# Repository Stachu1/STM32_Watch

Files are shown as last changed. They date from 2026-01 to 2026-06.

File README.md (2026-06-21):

# STM32 Watch


A minimalist, bare-metal wristwatch built around an STM32L0 microcontroller.
No HAL, no RTOS, no libraries. Just registers.

This is a fully custom PCB watch powered by a CR2032 coin cell, using 12 discrete LEDs arranged like a traditional analog dial. Time is displayed using LED “hands”, with additional modes for voltage, temperature, time setting, and a physics-based pendulum simulation.

## Features

### Core

- Ultra-low-power (STM32 Cortex-M0+)
- Bare-metal firmware
- RTC-based timekeeping using LSE (32.768 kHz)
- 12 discrete LEDs forming a clock dial
- Time-division multiplexing for LED control
- Two buttons for mode switching and wake-up from sleep

### Optional with IMU

- Absolute wrist tilt (AWT) wake-up
- Double tap to change LED brightness
- Pendulum simulation

## Modes

### Time display

- Hour hand: Static LED
- Minute hand: Slow fade in and out
- Subminutes (full rotation every 5min) hand: Quick fade in and out

### Statistics (Battery voltage, IMU/MCU temperature)

Battery voltage = Hour / 10 + 2V

(If hour hand is at 9 the battery voltage is 0.9V + 2V = 2.9V)

IMU/MCU temperature = Hour * 5°C + Minute * 0.1°C

(If hour hand is at 4 and minute hand is at 35 the temperature is 4 * 5°C + 35 * 0.1°C = 23.5°C)

### Time setting

Hour hand running in a circle indicated you are in the time setting mode.
Press Upper button to go into hour setting then press lower button to move the hour hand form 12 to 1, 2, 3 up to the current time. Confirm with the Upper button. Reapeat for minutes. After confirming minutes the watch will go back to Time display mode.

### Pendulum simulation

If the LEDs at 3 and 9 blink the IMU is disabled. You can enable it by pressing both buttons at once. This will enable the IMU and change mode to Time display.

IF the IMU is enbaled ther hour hand will behave like a pendulum with very low friction. I reacts to the acceleration vector in the XY plane so either tilting or moving the watch arround can cause the hour hand to move.

By double tapping the watch you can add 5 rotations a seconds to the pendulum in the current rotation direction.

If you wanna disalbe the IMU just press both buttons at once. The watch will disable the IMU and go back to the Time display mode.

## Mode changing

| *Current Mode* | *Action* | *Effect* |
|:-: | :-: | :- |
| Time display | Upper button | Change brightness |
| Time display | Double tap | Change brightness (if IMU enabled) |
| Time display | Lower button | Change mode to Stats (battery voltage) |
| Statistics | Upper button | Cycle stats (voltage/temperature) |
| Statistics | Lower button | Change mode to Time setting |
| Time setting | Upper button | Set hour/minute or confirm and change mode to Time display |
| Time setting | Lower button | Change mode to Pendulum simulation or increment hour/minute hand |
| Pendulum simulation | Upper button | Change brightness |
| Pendulum simulation | Double tap | Add +/- 5 rotations/second to the pendulum speed |
| Pendulum simulation | Upper & Lower buttons | Enable/Disable IMU (All the IMU features won't work if the IMU is disabled) |
| Pendulum simulation | Lower button | Change mode to Time display |

## Power Consumption

Tested on a CR2032 @ ~2.9V

| *Mode* | *Current* | *Wakeup* |
|:-: | :-: | :-: |
| Active (display on) | ~3mA | - |
| Stop mode (sleep) | 22uA | AWT or Buttons |
| Ultra low power (IMU off) | 5.5uA | Buttons |
| Stop mode, no IMU mounted | 2.3uA | Buttons |

## Hardware

- MCU: STM32L031
- IMU: LSM6DSM
- Timekeeping: built-in RTC with an external 32.768 kHz crystal
- Ambient light sensor (reverse-biased LED)
- Time display: 12 discrete LEDs
- Two push buttons
- Powered by a CR2032 battery








All LEDs are connected to ground through a single 100 Ω resistor, which is acceptable because only one LED is on at a time.

The RST pin has a single 100 nF capacitor, as there is an internal pull-up (~40 kΩ).

The I2C lines have external 10 kΩ pull-ups, but it would likely be possible to use weaker internal pull-ups if the frequency were reduced (not tested).

On the back side of the PCB, there are test points for SWD programming and UART debugging.

## Firmware

This project is intentionally low-level:

* Direct register access only
* No abstraction layers
* Tight control over timing and power
* Interrupt-driven architecture
* Fixed-point arithmetic (Q16.16)

### LED Driving

LEDs are updated in the IRQ handler, which runs every 100 µs. If a hand is to be shown, the LED is turned on at the beginning of its time slot and turned off when `local_step` reaches the hand’s brightness or at the end of the time slot. This approach ensures that only one LED is on at a time, limiting peak current and reducing battery voltage drop.

### Timekeeping

The STM32’s RTC runs on the low-speed external oscillator, and the time can be set by the user. Due to the high ESR of the crystal, the LSE drive strength had to be set to medium-high (`LSEDRV` in `RCC_CSR`).

### Sensors

The two interrupt pins on the LSM6DSM are used to detect double tap and absolute wrist tilt. Double tap is only available when the watch is awake, as it requires a significantly higher sampling rate.

Battery voltage is measured by reading the internal voltage reference and calculating the supply voltage. This works well, but due to the high internal resistance of the battery, the measured value is about 100 mV lower than the actual open-circuit voltage.

Temperature is measured using the IMU if it is enabled, or the internal temperature sensor of the MCU otherwise.

Ambient light sensing is not currently used, but it can be implemented by setting the pin connected to a reverse-biased LED high and then switching it to high-impedance input. The brighter it is, the faster the pin returns to a low state. Unfortunately, in very dark conditions this can take hundreds of milliseconds, which is why it is not used.

## Build System

This project uses a minimal build setup based on `build.c` and a nobuild-style workflow:
[https://github.com/tsoding/nob.h](https://github.com/tsoding/nob.h)

---

### Build

```bash
cd firmware
clang build.c -o build
./build build
```

---

### Build & Flash (ST-LINK + OpenOCD)

Solder ST-LINK SWD connections to the test points on the back. (Or just hold a pinheader on them)

```bash
./build flash
```

You can also flash the firmware using STM32CubeProgrammer.

---

## Firmware Size

```
text    data     bss     dec     hex filename
10304     56    4160   14520    38b8 firmware.elf
```

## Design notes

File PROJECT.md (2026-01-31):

# STM32 Watch:
This project is about maing a PCB watch that is based around an STM32, runs on a CR2032 battery, and displays time with 12 leds aranged in a circle. (Kinda like mechanical watches)

The goal is to learn more about PCB desing, STM32 enviorment and low-power features.

## Rev: A

### Features
* Powered by a CR2032
* STM32 MCU with SWD & UART communication
* The watch has two buttons
* Time is displayed through 12 leds arranged on a circle
* Ambiend light sensing
* IMU can be set into low-power and acceleratin can be read
* Wrist up interrupt detection
* Gesture control

### Buttons funcions
* Wake up from standby
* Time can be set
* Battery voltage can be checked
* Brightnes can be checked (1 - 2 - 3 - auto)
* Particle sim with a single LED showing a particle that reacts to watch acceleration
* Core tmeperature can be checked

### Finish Rev A by the end of March 2026

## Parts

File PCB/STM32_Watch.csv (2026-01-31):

Reference | Value | Footprint | Datasheet | Qty | LCSC | DNP | Exclude from BOM | Exclude from Board
BT1 | Battery_Cell | Battery:BatteryHolder_Renata_SMTU2032-LF_1x2032 | ~ | 1 | C18212226
C1,C4,C5,C6,C10,C11 | 100n | Capacitor_SMD:C_0603_1608Metric | ~ | 6 | C14663
C2,C3 | 18p | Capacitor_SMD:C_0603_1608Metric | ~ | 2 | C1647
C7 | 10u | Capacitor_SMD:C_0805_2012Metric | ~ | 1 | C32635
C8,C9 | 100u | Capacitor_SMD:C_1206_3216Metric | ~ | 2 | C15008
D1,D2,D3,D4,D5,D6,D7,D8,D9,D10,D11,D12,D13 | LED | LED_SMD:LED_0603_1608Metric | ~ | 13 | C965799
H1,H2 | MountingHole | STM32_Watch:StrapsConnection_20mm | ~ | 2 |  |  | Excluded from BOM
R1,R3,R4 | 10k | Resistor_SMD:R_0603_1608Metric | ~ | 3 | C98220
R2 | 100 | Resistor_SMD:R_0603_1608Metric | ~ | 1 | C105588
R5 | 1M | Resistor_SMD:R_0603_1608Metric | ~ | 1 | C105578
SW1,SW2 | SW_Push | STM32_Watch:SHOU_HAN_TS24CA |  | 2 | C393942
TP1,TP3,TP4,TP5,TP6,TP7,TP8 | TestPoint_Small | TestPoint:TestPoint_Pad_D1.5mm | ~ | 7
U1 | STM32L031K6Ux | Package_DFN_QFN:QFN-32-1EP_5x5mm_P0.5mm_EP3.1x3.1mm_ThermalVias | https://www.st.com/resource/en/datasheet/stm32l031k6.pdf | 1 | C2969821
U2 | LSM6DS3 | Package_LGA:LGA-14_3x2.5mm_P0.5mm_LayoutBorder3x4y | https://www.st.com/resource/en/datasheet/lsm6ds3tr-c.pdf | 1 | C94048
X1 | 32.768k | Crystal:Crystal_SMD_3215-2Pin_3.2x1.5mm |  | 1 | C5120559

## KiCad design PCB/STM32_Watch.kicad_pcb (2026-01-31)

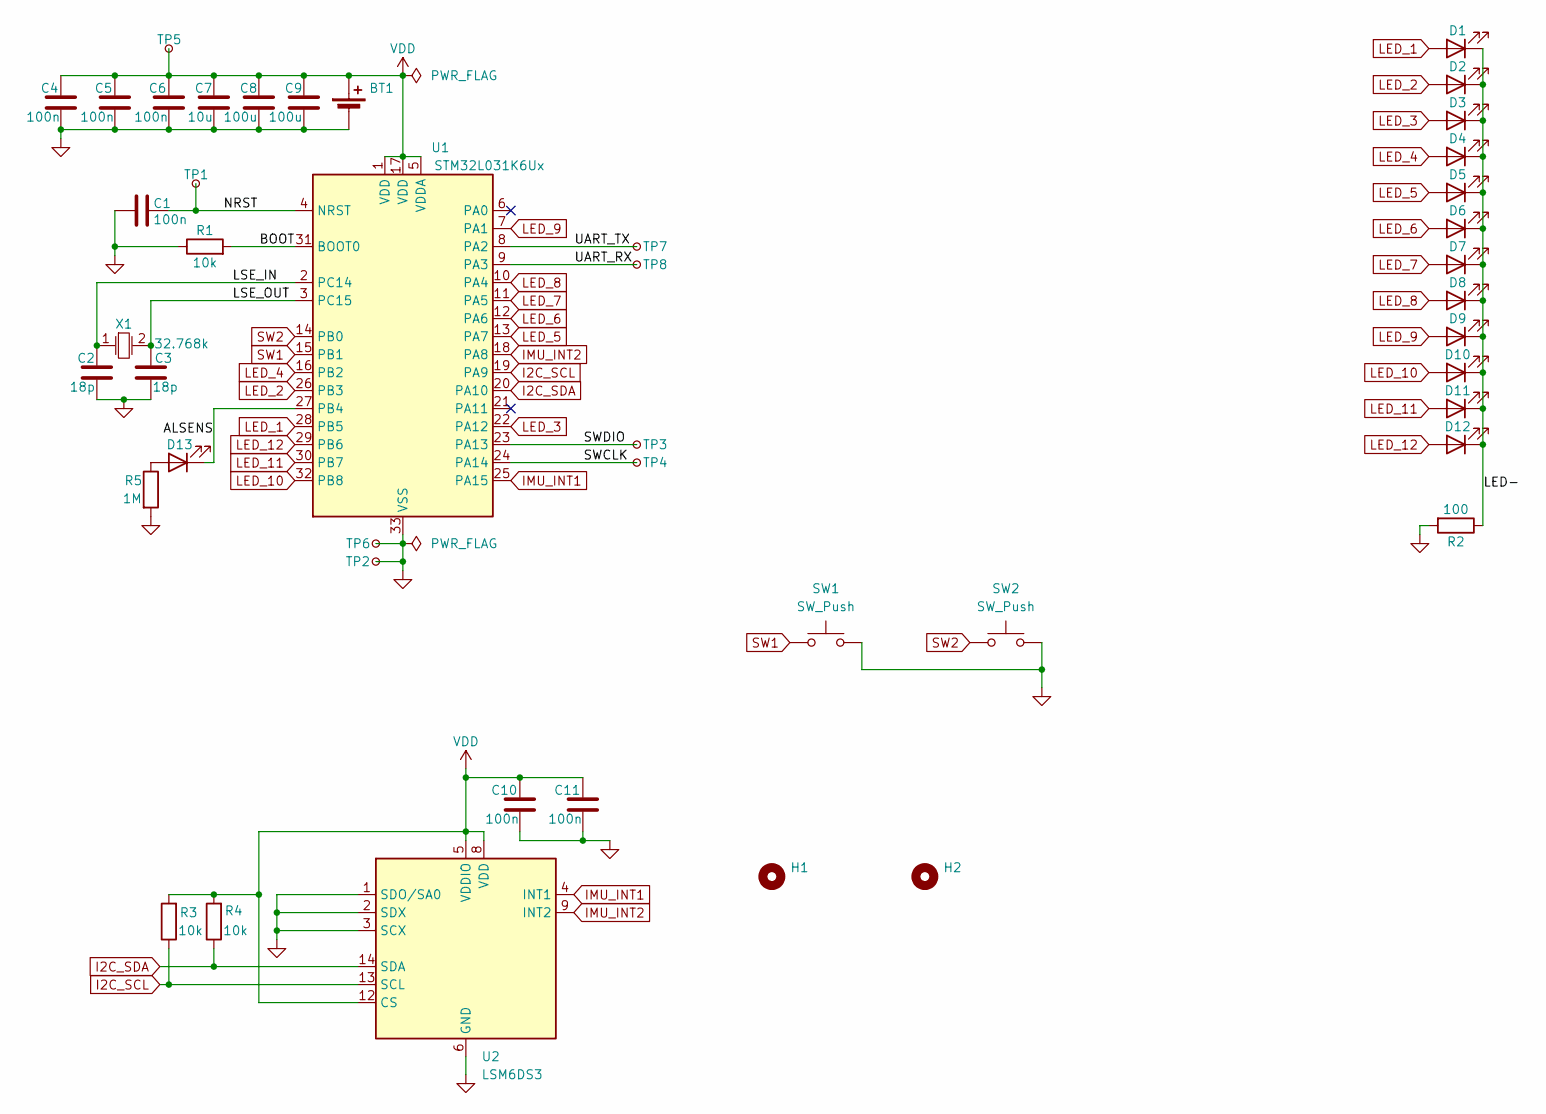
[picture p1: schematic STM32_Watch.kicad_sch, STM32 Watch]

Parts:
BT1: Battery_Cell; BatteryHolder_Renata_SMTU2032-LF_1x2032; LCSC C18212226
C1, C4, C5, C6, C10, C11: 100n; C_0603_1608Metric; LCSC C14663
C2, C3: 18p; C_0603_1608Metric; LCSC C1647
C7: 10u; C_0805_2012Metric; LCSC C32635
C8, C9: 100u; C_1206_3216Metric; LCSC C15008
D1, D2, D3, D4, D5, D6, D7, D8, D9, D10, D11, D12, D13: LED; LED_0603_1608Metric; LCSC C965799
H1, H2: MountingHole; StrapsConnection_20mm
R1, R3, R4: 10k; R_0603_1608Metric; LCSC C98220
R2: 100; R_0603_1608Metric; LCSC C105588
R5: 1M; R_0603_1608Metric; LCSC C105578
SW1, SW2: SW_Push; SHOU_HAN_TS24CA; LCSC C393942
TP1, TP2, TP3, TP4, TP5, TP6, TP7, TP8: TestPoint_Small; TestPoint_Pad_D1.5mm
U1: STM32L031K6Ux; QFN-32-1EP_5x5mm_P0.5mm_EP3.1x3.1mm_ThermalVias; LCSC C2969821
U2: LSM6DS3; LGA-14_3x2.5mm_P0.5mm_LayoutBorder3x4y; LCSC C94048
X1: 32.768k; Crystal_SMD_3215-2Pin_3.2x1.5mm; LCSC C5120559

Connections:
/ALSENS: D13.1 (K), U1.27 (PB4)
/BOOT: R1.2, U1.31 (BOOT0)
/LED-: D1.1 (K), D2.1 (K), D3.1 (K), D4.1 (K), D5.1 (K), D6.1 (K), D7.1 (K), D8.1 (K), D9.1 (K), D10.1 (K), D11.1 (K), D12.1 (K), R2.1
/LSE_IN: C2.2, U1.2 (PC14), X1.1
/LSE_OUT: C3.2, U1.3 (PC15), X1.2
/NRST: C1.1, TP1.1, U1.4 (NRST)
/SWCLK: TP4.1, U1.24 (PA14)
/SWDIO: TP3.1, U1.23 (PA13)
/UART_RX: TP8.1, U1.9 (PA3)
/UART_TX: TP7.1, U1.8 (PA2)
GND: BT1.2 (-), C1.2, C2.1, C3.1, C4.2, C5.2, C6.2, C7.2, C8.2, C9.2, C10.2, C11.2, R1.1, R2.2, R5.2, SW1.2, SW2.2, TP2.1, TP6.1, U1.33 (VSS), U2.1 (SDO/SA0), U2.2 (SDX), U2.3 (SCX), U2.6 (GND), U2.7 (GND)
I2C_SCL: R3.1, U1.19 (PA9), U2.13 (SCL)
I2C_SDA: R4.1, U1.20 (PA10), U2.14 (SDA)
IMU_INT1: U1.25 (PA15), U2.4 (INT1)
IMU_INT2: U1.18 (PA8), U2.9 (INT2)
LED_1: D1.2 (A), U1.28 (PB5)
LED_2: D2.2 (A), U1.26 (PB3)
LED_3: D3.2 (A), U1.22 (PA12)
LED_4: D4.2 (A), U1.16 (PB2)
LED_5: D5.2 (A), U1.13 (PA7)
LED_6: D6.2 (A), U1.12 (PA6)
LED_7: D7.2 (A), U1.11 (PA5)
LED_8: D8.2 (A), U1.10 (PA4)
LED_9: D9.2 (A), U1.7 (PA1)
LED_10: D10.2 (A), U1.32 (PB8)
LED_11: D11.2 (A), U1.30 (PB7)
LED_12: D12.2 (A), U1.29 (PB6)
unnamed: D13.2 (A), R5.1
SW1: SW1.1, U1.15 (PB1)
SW2: SW2.1, U1.14 (PB0)
VDD: BT1.1 (+), C4.1, C5.1, C6.1, C7.1, C8.1, C9.1, C10.1, C11.1, R3.2, R4.2, TP5.1, U1.1 (VDD), U1.5 (VDDA), U1.17 (VDD), U2.5 (VDDIO), U2.8 (VDD), U2.12 (CS)

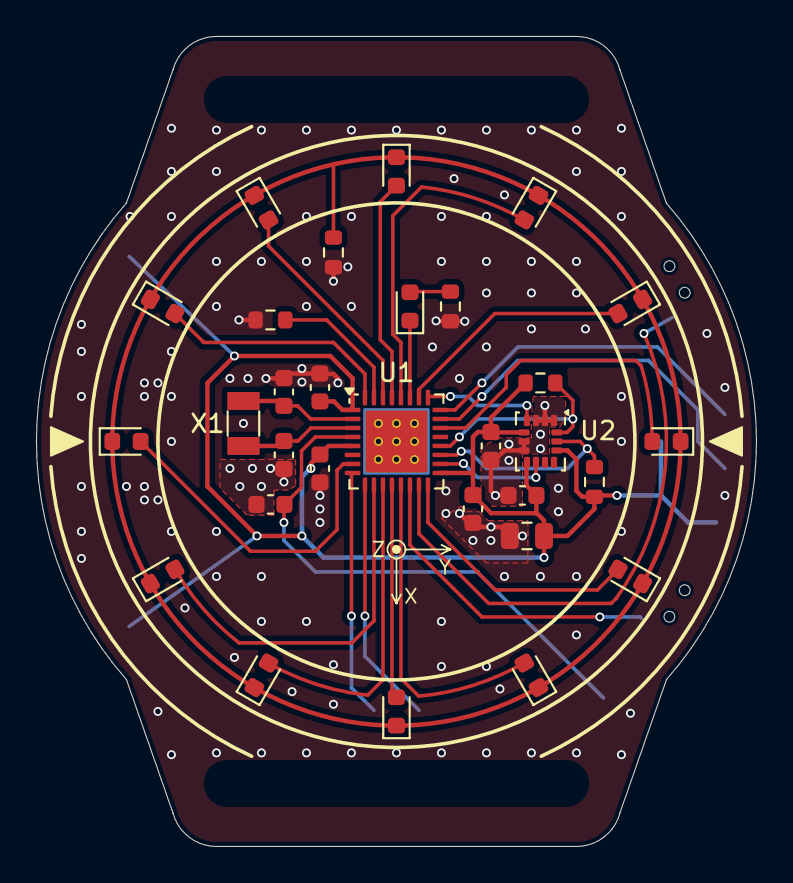
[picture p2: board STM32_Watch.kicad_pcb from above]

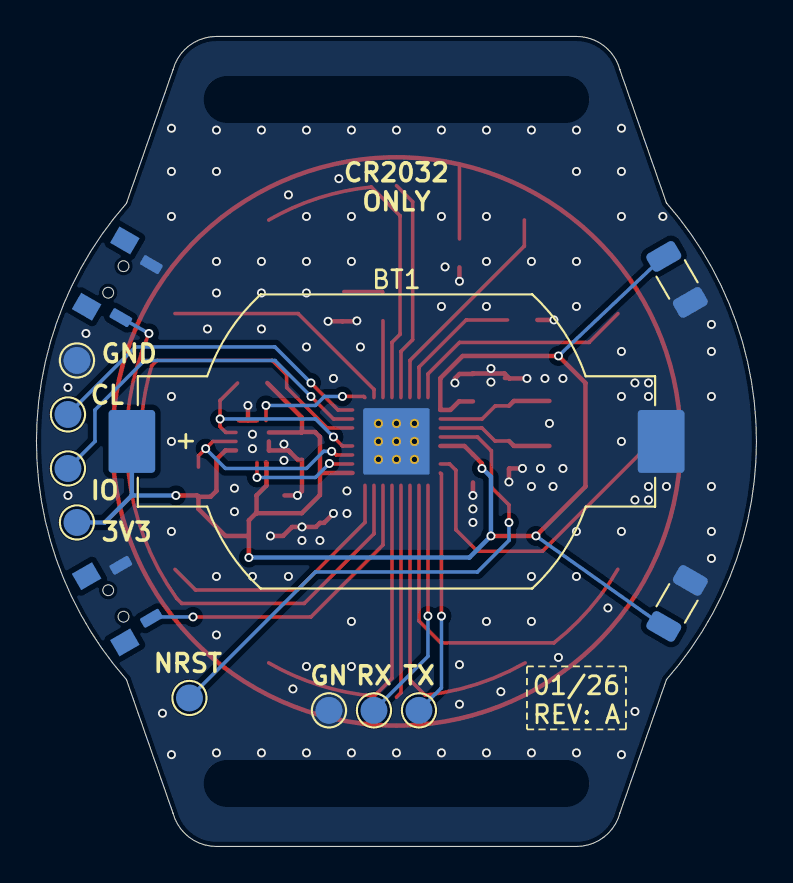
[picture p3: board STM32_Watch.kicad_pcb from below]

Board: 2 copper layers, 40.0 x 45.0 mm, 45 parts (13 on the bottom side), 31 nets.

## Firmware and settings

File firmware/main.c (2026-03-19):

#include "stm32l0x1_peripherals.h"
#include "intrin.h"
#include "types.h"

#define EVER (;;)
#define SYSCLK 2097000
#define BAUD 115200
#define TS_CAL1 *((u16*) 0x1FF8007A)
#define TS_CAL2 *((u16*) 0x1FF8007E)
#define VREFINT_CAL *((u16*) 0x1FF80078)
#define FIXED_SHIFT 16
#define FIXED_ONE (1 << FIXED_SHIFT)
#define IMU_ADDR 0x6A               // I2C address of the LSM6DSM IMU (SA0 pulled low)
#define MAX_BRIGHTNESS_LEVEL 6      // 1 << MAX_BRIGHTNESS_LEVEL = BRIGHTNESS_STEPS
#define MIN_BRIGHTNESS_LEVEL 3      // Lowest brightness level (too low causes flickering and instability in the effect)
#define BRIGHTNESS_STEPS (1 << MAX_BRIGHTNESS_LEVEL) // Number of steps in the brightness control (Impacts frame rate)
#define STATS_FRAME_TIME 50         // ms between each frame in the stats animation
#define SIM_DT 8                    // ms between each physics update in pendulum sim mode
#define SIM_FRICTION 160            // Friction applied to pendulums in pendulum sim mode (Q32)
#define SIM_AFTER_TAP_SPEED 327680  // Speed the pendulum is set to on double tap in pendulum sim mode (Q32)
#define SIM_INACTIVITY_THS 5500     // min speed before entering Stop Mode (Q32)1 = 2*Pi/s
#define INACTIVITY_TIMEOUT 5000     // ms of inactivity before entering Stop Mode
#define STATS_TIMEOUT 10000         // ms before switching entering Stope Mode from stats mode due to inactivity
#define DEBUG false                 // Set to true to enable debug prints over UART
#define USE_IMU true                // Set to false to disable IMU for ULP mode or if IMU is not mounted


typedef i32 q32;

typedef struct {
    u8 new_position;        // New position to set the hand to (1->12 0 for off)
    u8 position;            // position of the hand (1-12 0 for off)
    u8 brightness;          // Brightness of the hand (0-(BRIGHTNESS_STEPS-1))
    u8 tick;                // Tick counter for breathing effect
    u8 tick_div;            // Tick divider for breathing speed control
    b8 fading_in;           // Whether the hand is currently fading in or out
} Hand;

typedef struct {
    volatile u32* port;     // Pointer to GPIO port
    u8 pin;                 // Pin number for the LED
} LED;

typedef struct {
    b8 pressed;             // Button was pressed flag (set after release if press was valid)
    b8 down;                // Button is currently held down
    u32 state_history;      // BUtton state history for debouncing (1 bit per sample, 0 for pressed)
    u32 ignore_until;       // Millis until presses are ignored (used on wakeup and IMU toggle)
} BTN;

Hand hands[3] = {
    {0, 0, 0, 0, 0, true},  // Hour hand is static
    {0, 0, 0, 0, 5, true},  // Minute hand oscillates with tick_div of 5
    {0, 0, 0, 0, 1, true}   // Second hand oscillates with tick_div of 1
};

const volatile LED leds[] = {
    {(volatile u32*)GPIOB, 5},   // LED 1: PB5
    {(volatile u32*)GPIOB, 3},   // LED 2: PB3
    {(volatile u32*)GPIOA, 12},  // LED 3: PA12
    {(volatile u32*)GPIOB, 2},   // LED 4: PB2
    {(volatile u32*)GPIOA, 7},   // LED 5: PA7
    {(volatile u32*)GPIOA, 6},   // LED 6: PA6
    {(volatile u32*)GPIOA, 5},   // LED 7: PA5
    {(volatile u32*)GPIOA, 4},   // LED 8: PA4
    {(volatile u32*)GPIOA, 1},   // LED 9: PA1
    {(volatile u32*)GPIOB, 8},   // LED 10: PB8
    {(volatile u32*)GPIOB, 7},   // LED 11: PB7
    {(volatile u32*)GPIOB, 6}    // LED 12: PB6
};

// Sine LUT with 64 entries for 0-360 degrees (scaled to Q32)
const q32 SIN_LUT[64] = {
    0, 6423, 12785, 19024, 25079, 30893, 36409, 41575,
    46340, 50660, 54491, 57800, 60564, 62755, 64348, 65323,
    65636, 65323, 64348, 62755, 60564, 57800, 54491, 50660,
    46340, 41575, 36409, 30893, 25079, 19024, 12785, 6423,
    0, -6423, -12785, -19024, -25079, -30893, -36409, -41575,
    -46340, -50660, -54491, -57800, -60564, -62755, -64348, -65323,
    -65636, -65323, -64348, -62755, -60564, -57800, -54491, -50660,
    -46340, -41575, -36409, -30893, -25079, -19024, -12785, -6423
};

const u8 hex_table[16] = {'0', '1', '2', '3', '4', '5', '6', '7', '8', '9', 'A', 'B', 'C', 'D', 'E', 'F'};
BTN btn_up = {false, false, 0xFFFFFFFF, 0}, btn_down = {false, false, 0xFFFFFFFF, 0};
volatile u32 pwm_step = BRIGHTNESS_STEPS * 3;
volatile u8 sub_millis = 0;
u32 millis = 0;
u32 last_activity = 0;
u8 brightness_level = MAX_BRIGHTNESS_LEVEL;
b8 IMU_Enabled = USE_IMU;
b8 sim_double_tap = false;

enum Mode {
    MODE_TIME,
    MODE_VOLTAGE,
    MODE_TEMPERATURE,
    MODE_TIME_SETTING,
    MODE_PENDULUM_SIM
} current_mode;


void Spin(u32);
void Delay_us(u32);
void Delay_ms(u32);
void GPIO_Init(void);
void Button_State_Handler(void);
void Hands_Update_Handler(void);
void TIM21_Init(void);
void Hand_Set(u8, u8);
void UART_Init(void);
void UART_Deinit(void);
void Print_char(u8);
void Print_str(c*);
void Print_u32(u32);
void Print_i32(i32);
void Print_q32(q32);
u8 Ambient_Sense(void);
void ADC_Init(void);
void ADC_Deinit(void);
u32 ADC_Get_VDDA(void);
i32 ADC_Get_Temp(void);
void I2C_Init(void);
void I2C_Deinit(void);
void I2C_Write(u8, u8, u8*, u8);
void I2C_Read(u8, u8, u8*, u8);
void IMU_Init(void);
void IMU_Deinit(void);
void IMU_Get_Accel(i16*, i16*, i16*);
i32 IMU_Get_Temp(void);
void RTC_Init(void);
void RTC_Set_Time(u8, u8, u8);
void RTC_Get_Time(u8*, u8*, u8*);
void RTC_Wakeup_Init(void);
void RTC_Set_Hands(void);
void Mode_Handler(void);
void Mode_Voltage_Handler(b8);
void Mode_Temperature_Handler(b8);
void Mode_Time_Setting_Handler(b8);
void Mode_Pendulum_Sim_Handler(b8);
void Enter_Stop_Mode(void);
void Wakeup_Handler(void);


void main(void)
{
    GPIO_Init();
    TIM21_Init();
    UART_Init();
    ADC_Init();
    RTC_Init();
    RTC_Wakeup_Init();
    if (IMU_Enabled)
    {
        I2C_Init();
        IMU_Init();
    }

    RTC_Set_Time(10, 17, 30);
    RTC_Set_Hands();

    for EVER
    {
        Mode_Handler();

        if ((current_mode != MODE_VOLTAGE && current_mode != MODE_TEMPERATURE &&
            millis - last_activity > INACTIVITY_TIMEOUT) || (millis - last_activity > STATS_TIMEOUT))
        {
            Enter_Stop_Mode();
            Wakeup_Handler();
        }
    }
}

// ====== ISR ======

// TIM21 Interrupt Handler for SW PWM control of LEDs an Button state handling
// (3% CPU | 3us @ 32MHz ~ 96 cycles)
void TIM21_IRQ_Handler(void)
{
    // Clear the flag
    TIM21->SR &= ~TIM21_SR_UIF;

    // Update millis
    sub_millis++;
    if (sub_millis == 10) // ~10 kHz / 10 ~= 1 kHz for millis update
    {
        sub_millis = 0;
        millis++;

        // Update button state history
        Button_State_Handler();
    }

    // Begin new PWM cycle
    pwm_step++;
    if (pwm_step >= BRIGHTNESS_STEPS * 3)
    {
        // Reset pwm_step
        pwm_step = 0;

        // Update hands brightness and position for the next cycle
        Hands_Update_Handler();
    }

    // Get hand index for the current time slot
    u8 hand_idx = pwm_step / BRIGHTNESS_STEPS;
    u8 local_step = pwm_step % BRIGHTNESS_STEPS;

    // Turn off previous hand LED and turn on the LED for the current hand at the start of its brightness cycle
    if (local_step == 0)
    {
        // Turn off all LEDs
        GPIOA->BSRR = 0b1000011110010 << 16;
        GPIOB->BSRR = 0b111101100 << 16;

        if (hands[hand_idx].brightness > 0 && hands[hand_idx].position > 0)
        {
            u8 led_on = hands[hand_idx].position - 1;
            leds[led_on].port[6] = (1 << leds[led_on].pin);
        }
    }

    // Turn off the LED for the current hand at the end of its brightness cycle
    if (local_step >= hands[hand_idx].brightness && hands[hand_idx].position > 0)
    {
        u8 led_off = hands[hand_idx].position - 1;
        leds[led_off].port[6] = (1 << (leds[led_off].pin + 16));
    }
}

// 0.2Hz RTC Interrupt Handler for hands update
// (5.25us @ 32MHz ~ 168 cycles)
void RTC_IRQ_Handler(void)
{
    // Clear the flag
    EXTI->PR = EXTI_PR_PIF20;

    // Check if Wakeup Timer caused the interrupt
    if (RTC->ISR & RTC_ISR_WUTF) 
    {
        // Clear RTC Wakeup Flag
        RTC->WPR = 0xCA;
        RTC->WPR = 0x53;
        RTC->ISR &= ~RTC_ISR_WUTF;
        RTC->WPR = 0xFF; // Re-lock

        if (current_mode == MODE_TIME)
        {
            RTC_Set_Hands();
        }
    }
}

// EXTI Interrupt Handler for buttons
// (2us @ 32MHz ~ 64 cycles)
void EXTI0_1_IRQ_Handler(void)
{
    // Check PB0 btn_down
    if (EXTI->PR & (1 << 0))
    {
        EXTI->PR = (1 << 0); // Clear the flag
    }

    // Check PB1 btn_up
    if (EXTI->PR & (1 << 1))
    {
        EXTI->PR = (1 << 1); // Clear the flag
    }
    last_activity = millis;
}

// EXTI Interrupt Handler for IMU AWT & Double Tap
void EXTI4_15_IRQ_Handler(void)
{
    // Check PA8 (INT2 - Wrist Tilt)
    if (EXTI->PR & (1 << 8))
    {
        EXTI->PR = (1 << 8); // Clear the flag
    }

    // Check PA15 (INT1 - Double Tap)
    if (EXTI->PR & (1 << 15))
    {
        EXTI->PR = (1 << 15); // Clear the flag
        if (current_mode == MODE_PENDULUM_SIM)
        {
            sim_double_tap = true;
        }
        else
        {
            Print_str("Changing brightness\n");
            brightness_level = (brightness_level == MAX_BRIGHTNESS_LEVEL) ? MIN_BRIGHTNESS_LEVEL : brightness_level + 1;
            Hand_Set(0, hands[0].position);
            Hand_Set(1, hands[1].position);
            Hand_Set(2, hands[2].position);
        }
    }
    last_activity = millis;
}

// ====== Utility Functions ======

// Do nothing for 4 clock cyles
void Spin(u32 count)
{
    while (count--) __asm__ volatile ("nop");
}

// Delay microseconds based on Spin 
// (for delay above 100ms use Delay_ms)
void Delay_us(u32 us)
{
    u32 spins = (us * (SYSCLK/1000)) / 4000;
    Spin(spins);
}

// Delay milliseconds based on Delay_us
void Delay_ms(u32 ms)
{
    (void)ms;
    u32 hundereds = ms / 100;
    u32 rest = ms - hundereds * 100;
    for (u32 i=0; i<hundereds; i++)
    {
        Delay_us(100000);
    }
    Delay_us(rest * 1000);
}

// Init GPIOs for the LEDs
void GPIO_Init(void)
{
    // Enable GPIOA and GPIOB clocks
    RCC->IOPENR |= RCC_IOPENR_IOPAEN | RCC_IOPENR_IOPBEN;
    // Enable SYSCFG Clock
    RCC->APB2ENR |= RCC_APB2ENR_SYSCFGEN;

    // === LEDs ===
    // Set PA1, PA4, PA5, PA6, PA7, PA12 to output (MODE = 01)
    BF_SET(GPIOA->MODER, GPIOA_MODER_MODE1, 0x1);   // PA1 as output
    BF_SET(GPIOA->MODER, GPIOA_MODER_MODE4, 0x1);   // PA4 as output
    BF_SET(GPIOA->MODER, GPIOA_MODER_MODE5, 0x1);   // PA5 as output
    BF_SET(GPIOA->MODER, GPIOA_MODER_MODE6, 0x1);   // PA6 as output
    BF_SET(GPIOA->MODER, GPIOA_MODER_MODE7, 0x1);   // PA7 as output
    BF_SET(GPIOA->MODER, GPIOA_MODER_MODE12, 0x1);  // PA12 as output
    // Set PB2, PB3, PB5, PB6, PB7, PB8 to output (MODE = 01)
    BF_SET(GPIOB->MODER, GPIOB_MODER_MODE2, 0x1);   // PB2 as output
    BF_SET(GPIOB->MODER, GPIOB_MODER_MODE3, 0x1);   // PB3 as output
    BF_SET(GPIOB->MODER, GPIOB_MODER_MODE5, 0x1);   // PB5 as output
    BF_SET(GPIOB->MODER, GPIOB_MODER_MODE6, 0x1);   // PB6 as output
    BF_SET(GPIOB->MODER, GPIOB_MODER_MODE7, 0x1);   // PB7 as output
    BF_SET(GPIOB->MODER, GPIOB_MODER_MODE8, 0x1);   // PB8 as output

    // === UART ===
    if (DEBUG)
    {
        // Set alterative pin func
        BF_SET(GPIOA->MODER, GPIOA_MODER_MODE2, 0x2);   // PA2
        BF_SET(GPIOA->MODER, GPIOA_MODER_MODE3, 0x2);   // PA3
        // Enable alterative func
        BF_SET(GPIOA->AFRL, GPIOA_AFRL_AFSEL2, 0x4);    // PA2
        BF_SET(GPIOA->AFRL, GPIOA_AFRL_AFSEL3, 0x4);    // PA3
    }

    // === I2C ===
    if (USE_IMU)
    {
    // Set alterative pin func
    BF_SET(GPIOA->MODER, GPIOA_MODER_MODE9, 0x2);   // PA9
    BF_SET(GPIOA->MODER, GPIOA_MODER_MODE10, 0x2);  // PA10
    // Set output open-drain
    GPIOA->OTYPER |= (GPIOA_OTYPER_OT9 | GPIOA_OTYPER_OT10);
    // Set high speed
    BF_SET(GPIOA->OSPEEDR, GPIOA_OSPEEDR_OSPEED9, 0x2);
    BF_SET(GPIOA->OSPEEDR, GPIOA_OSPEEDR_OSPEED10, 0x2);
    // Enable alterative func
    BF_SET(GPIOA->AFRH, GPIOA_AFRH_AFSEL9, 0x1);    // PA9
    BF_SET(GPIOA->AFRH, GPIOA_AFRH_AFSEL10, 0x1);   // PA10

    // === EXTI for IMU Interrupts ===
    // Configure PA8 and PA15 as Input
    BF_SET(GPIOA->MODER, GPIOA_MODER_MODE8, 0x0);
    BF_SET(GPIOA->MODER, GPIOA_MODER_MODE15, 0x0);
    // Map PA8 and PA15 to EXTI Line 8 and 15
    BF_SET(SYSCFG_COMP->EXTICR3, SYSCFG_COMP_EXTICR3_EXTI8, 0x0);
    BF_SET(SYSCFG_COMP->EXTICR4, SYSCFG_COMP_EXTICR4_EXTI15, 0x0);
    // Enable Rising Edge triggers
    EXTI->RTSR |= (EXTI_RTSR_RT8 | EXTI_RTSR_RT15);
    EXTI->IMR  |= (EXTI_IMR_IM8 | EXTI_IMR_IM15);
    // Enable EXTI4_15 Interrupt (IRQ 7)
    NVIC->ISER |= (1 << 7);
    }

    // === Buttons ===
        // Configure PB0 and PB1 as Input
    BF_SET(GPIOB->MODER, GPIOB_MODER_MODE0, 0x0);   // PB0 as input
    BF_SET(GPIOB->MODER, GPIOB_MODER_MODE1, 0x0);   // PB1 as input
    // Enable Internal Pull-Ups
    BF_SET(GPIOB->PUPDR, GPIOB_PUPDR_PUPD0, 0x1);
    BF_SET(GPIOB->PUPDR, GPIOB_PUPDR_PUPD1, 0x1);
    // Map PB0 and PB1 to EXTI Line 0 and 1
    BF_SET(SYSCFG_COMP->EXTICR1, SYSCFG_COMP_EXTICR1_EXTI0, 0x1); // PB0
    BF_SET(SYSCFG_COMP->EXTICR1, SYSCFG_COMP_EXTICR1_EXTI1, 0x1); // PB1
    // Enable Falling Edge triggers
    EXTI->FTSR |= (EXTI_FTSR_FT0 | EXTI_FTSR_FT1); // Press
    EXTI->IMR  |= (EXTI_IMR_IM0 | EXTI_IMR_IM1);   // Unmask
    // Enable EXTI0_1 Interrupt (IRQ 5)
    NVIC->ISER |= (1 << 5);
}

// Button state handler called every 1ms in the TIM21 IRQ Handler
void Button_State_Handler(void)
{
    // Update button state history
    btn_down.state_history = (btn_down.state_history << 1) | (GPIOB->IDR & (1 << 0) ? 1 : 0);
    btn_up.state_history = (btn_up.state_history << 1) | (GPIOB->IDR & (1 << 1) ? 1 : 0);

    // Check state_history for stable press or release
    if ((btn_down.state_history & 0xFF) == 0)
    {
        btn_down.down = true;
    }
    else if ((btn_down.state_history & 0xFF) == 0xFF)
    {
        if (btn_down.down)
        {
            if (millis > btn_down.ignore_until) btn_down.pressed = true;
            btn_down.down = false;
        }
    }

    if ((btn_up.state_history & 0xFF) == 0)
    {
        btn_up.down = true;
    }
    else if ((btn_up.state_history & 0xFF) == 0xFF)
    {
        if (btn_up.down)
        {
            if (millis > btn_up.ignore_until) btn_up.pressed = true;
            btn_up.down = false;
        }
    }
}

// Hands handler called every 3*BRIGHTNESS_STEPS ms in the TIM21 IRQ Handler
void Hands_Update_Handler(void)
{
    for (u8 i=0; i<3; i++)
    {
        // Update hand position to new_position
        // (prevents ghosting when hand position changes durring its time slot)
        if (hands[i].new_position != 255)
        {
            hands[i].position = hands[i].new_position;    // Update hand position to new_position
            hands[i].new_position = 255;               // Reset new_position
            if ((1 << brightness_level) < hands[i].brightness)
            {
                // Make sure max brightness is not exceeded (Hands are reset every brightness change)
                hands[i].brightness = (1 << brightness_level);
            }
        }

        // Set brightness and continue if hand is static
        if (hands[i].tick_div == 0)
        {
            hands[i].brightness = (1 << brightness_level);
            continue;
        };

        // Update tick and handle breathing effect
        hands[i].tick++;
        if (hands[i].tick == hands[i].tick_div)
        {
            // Reset tick and update brightness
            hands[i].tick = 0;
            u8 b_step = (1 << (brightness_level - MIN_BRIGHTNESS_LEVEL));
            if (hands[i].fading_in)
            {
                // Increase brightness until max, then start fading out
                if (hands[i].brightness + b_step > (1 << brightness_level))
                {
                    hands[i].fading_in = false;
                    hands[i].brightness -= b_step;
                }
                else hands[i].brightness += b_step;
            }
            else
            {
                // Decrease brightness until min, then start fading in
                if (hands[i].brightness - b_step < 0)
                {
                    hands[i].fading_in = true;
                    hands[i].brightness += b_step;
                }
                else hands[i].brightness -= b_step;
            }
        }
    }
}

// Init TIM21 and enable its interrupt
// for SW PWM control of the LEDs and ms couunting
void TIM21_Init(void)
{
    // Enable TIM21 peripheral clock
    RCC->APB2ENR |= RCC_APB2ENR_TIM21EN;

    // Run at SYSCLK with no prescaler aiming for 10kHz frequency
    TIM21->PSC = 0;
    TIM21->ARR = SYSCLK / 10000;
    
    // Enable update interrupt and start counter
    TIM21->DIER |= TIM21_DIER_UIE;
    TIM21->CR1 |= TIM21_CR1_CEN;

    // Enable TIM21 interrupt in NVIC
    NVIC->ISER |= (1 << 20);
}

// Set the position of a hand (1-12, 0 for off)
inline void Hand_Set(u8 hand_index, u8 position)
{
    if (hand_index > 2 || position > 12) return;
    hands[hand_index].new_position = position;
}

// Init UART at #BUAD
void UART_Init(void)
{
    if (!DEBUG) return;

    // Enable peripheral clock
    RCC->APB1ENR |= RCC_APB1ENR_USART2EN;

    // Disable USART
    USART2->CR1 &= ~USART2_CR1_UE;

    // Set word len, Parity ctrl, 1 Stop bit, Enable TX
    USART2->CR1 &= ~(USART2_CR1_M0 | USART2_CR1_M1);
    USART2->CR1 &= ~USART2_CR1_PCE;
    BF_SET(USART2->CR2,USART2_CR2_STOP, 0x0);
    USART2->CR1 |= USART2_CR1_TE;

    // Set USART div (sysclk / baud_rate)
    USART2->BRR = (SYSCLK / BAUD) & 0xFFFF;         

    // Enable USART
    USART2->CR1 |= USART2_CR1_UE;
}

// Deinit UART
void UART_Deinit(void)
{
    // Disable UART
    USART2->CR1 &= ~USART2_CR1_UE;

    // Reset UART
    RCC->APB1RSTR |= RCC_APB1RSTR_USART2RST;
    RCC->APB1RSTR &= ~RCC_APB1RSTR_USART2RST;

    // Set PA2 and PA3 back to Analog Mode (0x3)
    BF_SET(GPIOA->MODER, GPIOA_MODER_MODE2, 0x3);
    BF_SET(GPIOA->MODER, GPIOA_MODER_MODE3, 0x3);

    // Clear AF selection
    BF_SET(GPIOA->AFRL, GPIOA_AFRL_AFSEL2, 0x0);
    BF_SET(GPIOA->AFRL, GPIOA_AFRL_AFSEL3, 0x0);

    // Disable peripheral clock
    RCC->APB1ENR &= ~RCC_APB1ENR_USART2EN;
}

// Sends char over UART
void Print_char(u8 c)
{
    if (!DEBUG) return;
    while (!(USART2->ISR & USART2_ISR_TXE)) Spin(1);
    BF_SET(USART2->TDR, USART2_TDR_TDR, c);
}

// Sends string over UART
void Print_str(c *str)
{
    if (!DEBUG) return;
    while (*str)
    {
        Print_char(*(str++));
    }
}

// Sends u32 over UART
void Print_u32(u32 num)
{
    if (!DEBUG) return;
    if (num == 0)
    {
        Print_char('0');
        return;
    }

    u8 digits[10];  
    u32 num_len = 0;

    while (num)
    {
        digits[num_len++] = '0' + (num % 10);
        num /= 10;
    }

    for (u32 i=num_len; i>0; i--)
    {
        Print_char(digits[i - 1]);
    }
}

// Sends i32 over UART
void Print_i32(i32 num)
{
    if (!DEBUG) return;
    if (num == 0)
    {
        Print_char('0');
        return;
    }

    b32 is_neg = (num < 0) ? true : false;
    if (is_neg) num = -num;

    u8 digits[10];  
    u32 num_len = 0;

    while (num)
    {
        digits[num_len++] = '0' + (num % 10);
        num /= 10;
    }

    if (is_neg) Print_char('-');
    for (u32 i=num_len; i>0; i--)
    {
        Print_char(digits[i - 1]);
    }
}

// Sends q32 (q16.16) over UART
void Print_q32(q32 num)
{
    if (!DEBUG) return;
    if (num == 0)
    {
        Print_str("0.0000");
        return;
    }

    if (num < 0)
    {
        Print_char('-');
        num = -num;
    }

    u32 int_part = (u32)(num >> FIXED_SHIFT);
    u32 frac_part = ((u32)(num & (FIXED_ONE - 1)) * 10000) >> FIXED_SHIFT;

    Print_u32(int_part);
    Print_char('.');

    // Print leading zeros for the fraction
    if (frac_part < 1000) Print_char('0');
    if (frac_part < 100)  Print_char('0');
    if (frac_part < 10)   Print_char('0');
    
    Print_u32(frac_part);
}

// Get Ambient light intensity
// May take a while in low light (~500ms)
u8 Ambient_Sense(void)
{
    u32 ambl = 0;
    BF_SET(GPIOB->MODER, GPIOB_MODER_MODE4, 0x1);   // PB4 as output
    GPIOB->BSRR |= GPIOB_BSRR_BS4;
    Delay_ms(1);
    BF_SET(GPIOB->MODER, GPIOB_MODER_MODE4, 0x0);   // PB4 as input
    while (GPIOB->IDR & GPIOB_IDR_ID4 && ambl != 2080768) ambl++;
    return (u8)(255 - (ambl >> 13));
}

// Init ADC for measuring battery voltage and core temperature
void ADC_Init(void)
{
    // Enable peripheral clock and set ADC clock to PCLK/2
    RCC->APB2ENR |= RCC_APB2ENR_ADCEN;
    BF_SET(ADC->CFGR2, ADC_CFGR2_CKMODE, 0x1);

    // Disable ADC
    if (ADC->CR & ADC_CR_ADEN)
    {
        ADC->CR |= ADC_CR_ADDIS;
        while (ADC->CR & ADC_CR_ADEN) Spin(1);
    }

    // Calibration
    ADC->CR |= ADC_CR_ADCAL;
    while (ADC->CR & ADC_CR_ADCAL) Spin(1);

    // Config ADC
    ADC->CFGR1 |= ADC_CFGR1_DISCEN;
    ADC->CFGR1 &= ~ADC_CFGR1_CONT;
    ADC->CCR |= (ADC_CCR_TSEN | ADC_CCR_VREFEN);
    ADC->SMPR |= ADC_SMPR_SMPR_WIDTH;

    // Configure Oversampling x256 & 8 bit shift
    ADC->CFGR2 |= ADC_CFGR2_OVSE;
    BF_SET(ADC->CFGR2, ADC_CFGR2_OVSR, 0x7);
    BF_SET(ADC->CFGR2, ADC_CFGR2_OVSS, 0x8);

    // Enable ADC
    ADC->ISR |= ADC_ISR_ADRDY;
    ADC->CR |= ADC_CR_ADEN;
    while (!(ADC->ISR & ADC_ISR_ADRDY)) Spin(1);
}

// Deinit ADC
void ADC_Deinit(void)
{
    // Stop ongoint conversions
    if (ADC->CR & ADC_CR_ADSTART)
    {
        ADC->CR |= ADC_CR_ADSTP;
        while (ADC->CR & ADC_CR_ADSTP) Spin(1);
    }

    // Disable ADC
    if (ADC->CR & ADC_CR_ADEN)
    {
        ADC->CR |= ADC_CR_ADDIS;
        while (ADC->CR & ADC_CR_ADEN) Spin(1);
    }

    // Disable voltage references
    ADC->CCR &= ~(ADC_CCR_TSEN | ADC_CCR_VREFEN);

    // Disable ADC voltage regulator
    ADC->CR |= ADC_CR_ADVREGEN;

    // Disable peripheral clock
    RCC->APB2ENR &= ~RCC_APB2ENR_ADCEN;
}
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

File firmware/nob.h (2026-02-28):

/* nob - v3.2.2 - Public Domain - https://github.com/tsoding/nob.h

   This library is the next generation of the [NoBuild](https://github.com/tsoding/nobuild) idea.

   # Quick Example

      ```c
      // nob.c
      #define NOB_IMPLEMENTATION
      #include "nob.h"

      int main(int argc, char **argv)
      {
          NOB_GO_REBUILD_URSELF(argc, argv);
          Nob_Cmd cmd = {0};
          nob_cmd_append(&cmd, "cc", "-Wall", "-Wextra", "-o", "main", "main.c");
          if (!nob_cmd_run(&cmd)) return 1;
          return 0;
      }
      ```

      ```console
      $ cc -o nob nob.c
      $ ./nob
      ```

      The `nob` automatically rebuilds itself if `nob.c` is modified thanks to
      the `NOB_GO_REBUILD_URSELF` macro (don't forget to check out how it works below)

   # Stripping off `nob_` Prefixes

      Since Pure C does not have any namespaces we prefix each name of the API with the `nob_` to avoid any
      potential conflicts with any other names in your code. But sometimes it is very annoying and makes
      the code noisy. Because of that you can drop the `nob_` prefix.

      ```c
      // nob.c
      #define NOB_IMPLEMENTATION
      #include "nob.h"

      int main(int argc, char **argv)
      {
          GO_REBUILD_URSELF(argc, argv);
          Cmd cmd = {0};
          cmd_append(&cmd, "cc", "-Wall", "-Wextra", "-o", "main", "main.c");
          if (!cmd_run(&cmd)) return 1;
          return 0;
      }
      ```

      If the lack of prefixes causes any problems you can disable the prefix stripping by defining
      `NOB_UNSTRIP_PREFIX` feature macro before including "nob.h".

      Not all the names have strippable prefixes. All the redefinable names like `NOB_REBUILD_URSELF`
      for instance will retain their prefix always. Notable exception is the nob_log() function. Stripping
      away the prefix results in log() which was historically always referring to the natural logarithmic
      function that is already defined in math.h. So there is no reason to strip off the prefix for nob_log().
      Another exception is nob_rename() which collides with the widely known POSIX function rename(2) if you
      strip the prefix off.

      The prefixes are stripped off only on the level of the preprocessor. The names of the functions in the
      compiled object file will still retain the `nob_` prefix. Keep that in mind when you FFI with nob.h
      from other languages (for whatever reason).

      If only few specific names create conflicts for you, you can just #undef those names after the
      `#include <nob.h>` without enabling `NOB_UNSTRIP_PREFIX` since they are macros anyway.

   # Macro Interface

      All these macros are `#define`d by the user before including nob.h

   ## Flags

      Enable or disable certain aspects of nob.h

      - NOB_IMPLEMENTATION - Enable definitions of the functions. By default only declarations are included.
        See https://github.com/nothings/stb/blob/f58f558c120e9b32c217290b80bad1a0729fbb2c/docs/stb_howto.txt
        for more info.
      - NOB_WARN_DEPRECATED - Warn about the usage of deprecated function. We rarely actually remove deprecated functions,
        but if you want to know what is discouraged you may want to enable this flag.
      - NOB_EXPERIMENTAL_DELETE_OLD - Experimental feature that automatically removes `nob.old` files. It's unclear how well
        it works on Windows, so it's experimental for now.
      - NOB_UNSTRIP_PREFIX - do not strip the `nob_` prefixes from non-redefinable names.
      - NOB_NO_ECHO - do not echo the actions various nob functions are doing (like nob_cmd_run(), nob_mkdir_if_not_exists(), etc).

   ## Redefinable Macros

      Redefine default behaviors of nob.h.

      - NOBDEF - Appends additional things to function declarations. You can do something like `#define NOBDEF static inline`.
      - NOB_ASSERT(condition) - Redefine which assert() nob.h shall use.
      - NOB_REALLOC(oldptr, size) - Redefine which realloc() nob.h shall use.
      - NOB_FREE(ptr) - Redefine which free() nob.h shall use.
      - NOB_DEPRECATED(message) - Redefine how nob.h shall mark functions as deprecated.
      - NOB_DA_INIT_CAP - Redefine initial capacity of Dynamic Arrays.
      - NOB_TEMP_CAPACITY - Redefine the capacity of the temporary storate.
      - NOB_REBUILD_URSELF(binary_path, source_path) - redefine how nob.h shall rebuild itself.
      - NOB_WIN32_ERR_MSG_SIZE - Redefine the capacity of the buffer for error message on Windows.
*/

#ifndef NOB_H_
#define NOB_H_
#ifdef _WIN32
#    ifndef _CRT_SECURE_NO_WARNINGS
#        define _CRT_SECURE_NO_WARNINGS (1)
#    endif // _CRT_SECURE_NO_WARNINGS
#endif //  _WIN32

#ifndef NOBDEF
/*
   Goes before declarations and definitions of the nob functions. Useful to `#define NOBDEF static inline`
   if your source code is a single file and you want the compiler to remove unused functions.
*/
#define NOBDEF
#endif /* NOBDEF */

#ifndef NOB_ASSERT
#include <assert.h>
#define NOB_ASSERT assert
#endif /* NOB_ASSERT */

#ifndef NOB_REALLOC
#include <stdlib.h>
#define NOB_REALLOC realloc
#endif /* NOB_REALLOC */

#ifndef NOB_FREE
#include <stdlib.h>
#define NOB_FREE free
#endif /* NOB_FREE */

#ifdef NOB_WARN_DEPRECATED
#    ifndef NOB_DEPRECATED
#        if defined(__GNUC__) || defined(__clang__)
#            define NOB_DEPRECATED(message) __attribute__((deprecated(message)))
#        elif defined(_MSC_VER)
#            define NOB_DEPRECATED(message) __declspec(deprecated(message))
#        else
#            define NOB_DEPRECATED(...)
#        endif
#    endif /* NOB_DEPRECATED */
#else
#    define NOB_DEPRECATED(...)
#endif /* NOB_WARN_DEPRECATED */

#include <stdbool.h>
#include <stdint.h>
#include <stdlib.h>
#include <stdio.h>
#include <stdarg.h>
#include <string.h>
#include <errno.h>
#include <ctype.h>
#include <limits.h>
#include <time.h>

#ifdef _WIN32
#    define WIN32_LEAN_AND_MEAN
#    define _WINUSER_
#    define _WINGDI_
#    define _IMM_
#    define _WINCON_
#    include <windows.h>
#    include <direct.h>
#    include <io.h>
#    include <shellapi.h>
#else
#    ifdef __APPLE__
#        include <mach-o/dyld.h>
#    endif
#    ifdef __FreeBSD__
#        include <sys/sysctl.h>
#    endif
#    include <sys/types.h>
#    include <sys/wait.h>
#    include <sys/stat.h>
#    include <unistd.h>
#    include <fcntl.h>
#    include <dirent.h>
#endif

#ifdef __HAIKU__
#   include <image.h>
#endif

#ifdef _WIN32
#    define NOB_LINE_END "\r\n"
#else
#    define NOB_LINE_END "\n"
#endif
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

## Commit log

2025-12-14 Minimal schematics for the MCU and charging
    [STM32_Watch.kicad_pcb, STM32_Watch.kicad_sch]
2025-12-16 Li-po & usb charging -> CR2032 added magnetometer
    [STM32_Watch.kicad_pcb, STM32_Watch.kicad_sch]
2025-12-16 Added net lables & ERC fixes
    [STM32_Watch.kicad_pcb, STM32_Watch.kicad_sch]
2026-01-27 Added ALSENS for ambient light measurments
    [STM32_Watch.kicad_pcb, STM32_Watch.kicad_sch]
2026-01-28 Realigned components & Removed boot TP
    [STM32_Watch.kicad_pcb, STM32_Watch.kicad_sch]
2026-01-28 IMU instead of a compass
    [STM32_Watch.kicad_pcb, STM32_Watch.kicad_sch]
2026-01-28 Rearanged mcu pins & Routed
    [STM32_Watch.kicad_pcb, STM32_Watch.kicad_sch]
2026-01-29 Updated Routing & Fixed DRC problems
    [STM32_Watch.kicad_pcb, STM32_Watch.kicad_sch]
2026-01-29 Added silkscreen stuff
    [STM32_Watch.kicad_pcb]
2026-01-29 Rerouted 100uF caps & Via/Pad hole size 0.2->0.3
    [STM32_Watch.kicad_pcb]
2026-01-30 Improved routing
    [STM32_Watch.kicad_pcb]
2026-01-31 Added GND TP & BOM file
    [STM32_Watch.csv, STM32_Watch.kicad_pcb, STM32_Watch.kicad_sch]
2026-01-31 Vias dim 0.4 -> 0.5
    [STM32_Watch.kicad_pcb]
2026-02-28 Added FW & moved PCB stuff into PCB dir
    [STM32_Watch.csv, STM32_Watch.kicad_pcb, STM32_Watch.kicad_sch]
2026-03-01 Refactored LED control with Time-Division Multiplexing HW timers
2026-03-07 Updated LED driver & Added brightness ctrl
2026-03-10 Added sleep mode and IMU interrupts
2026-03-14 ULP sleep 21uA @ 3V with AWT wakeup enabled
2026-03-14 Use MSI @ 4MHz instead of PLL @ 32MHz | 1.5-4mA when awake
2026-03-15 Tap detection only in Z axis
2026-03-15 Updated button state logic & Moved hands logic to its handler
2026-03-15 Added IMU pwr down mode | ~3mA awake, 22uA sleep, 5.5uA ULP sleep IMU off
2026-03-15 Better stats animation & Auto choose imu/mcu temp sensor
2026-03-15 Fixed I2C Init/Deinit bug
    [main.c]
2026-03-17 Power saving & Temperature reading bug fixes
    [main.c]
2026-03-18 Hands logic bug fixes
    [main.c]
2026-06-21 Fix formatting in temperature calculation example
    Correct formatting of temperature calculation example in README.

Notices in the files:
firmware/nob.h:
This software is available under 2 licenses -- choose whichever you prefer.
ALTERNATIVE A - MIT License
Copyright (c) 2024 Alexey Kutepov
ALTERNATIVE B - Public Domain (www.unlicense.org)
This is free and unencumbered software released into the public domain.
